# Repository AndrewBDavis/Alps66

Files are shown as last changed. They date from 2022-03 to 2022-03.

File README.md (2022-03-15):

ALPS 66% keyboard PCB
=====================
The primary goal of this project was to design a PCB and plate which fits in KBD66 and FC660m cases and supports FC660m, FC660c and 66% AEK style layouts.
The pcb schematic is modified from Hasu's Alps64.

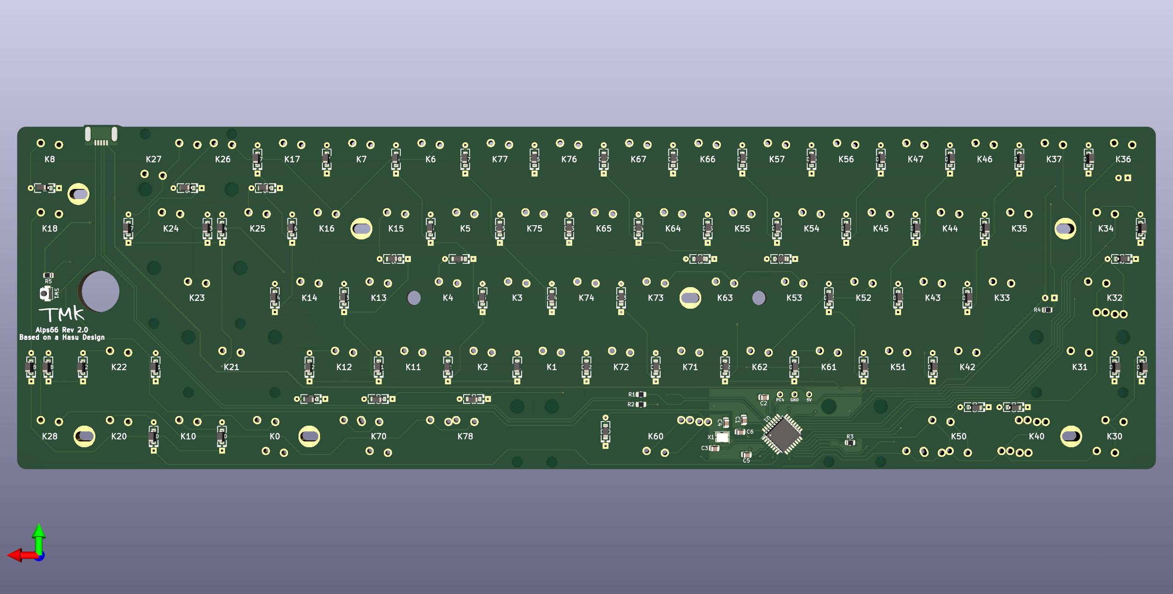
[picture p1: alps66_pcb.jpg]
alps66_pcb


original_b78a812e-5f5d-4627-9017-195e72d05074_PXL_20211022_134126410
Shown in FC660M case with prototype 1.2mm FR4 Plate in FC660C Layout

Supported Layouts
---------------
No ISO Enter (Especially ISO AEK)

Rev1 boards only:
	To utilize split backspace or 3rd key to the right of spacebar, you will need to solder bridge SJ1.
	To utilize the LED indicator, you will need to solder bridge SJ2 and modify files. 

Bottom row:
	1.5__1.0___1.5___6.5___1.5___1.5___1__1__1		(AEK with and 1u option key)

	1.5__1.25__1.5___6.25__1.5___1.5___1__1__1		(AEK Standard with 6.25 spacebar)

	1.5__1.25__1.5___5__1.5___1.25___1.5___1__1__1		(AEK Standard with 5 spacebar)
	
	1.25__1.25__1.25__6__1.25__1.25__1.25__1__1__1		(FC660c bottom row)
	
	1.25__1.0___1.25__6.25__1.25__1.25__1.25__1__1__1	(FC660m bottom row)

Caps lock:  
	0.75u  (Non Stepped)  
	0.25u  (Alps Dell/SGI Stepped)  
	0.125u (Cherry Stepped)  

Where key unit for rows: Esc[0u], 1[1u]...

Supported Cases
-------------
KBDFans KBD66 (confirmed)  
Leopold FC660m (confirmed)  
KBDFans KBD661 (unconfirmed)  

BOM for Alps66 keyboard                                                  
------------------
| REF:  | VALUE: | FOOTPRINT: | COMPONENT |
|--- | --- | --- | --- |
| C1 | 4.7u | C_0805 | |
| C2 | 1u | C_0805 | | 
| C3 | 22p | C_0805 | |
| C4 | 22p | C_0805 | |
| C5 | 0.1u | C_0805 | |
| C6 | 0.1u | C_0805 | |
| J1 | USB_mini_B | USB_miniB_hirose_5S8 | UX60SC-MB-5S8 Hirose |
| R1 | 22 | R_0805 | |
| R2 | 22 | R_0805 | |
| R3 | 10K | R_0805 | |
| R4 | 1K | R_0805 | |
| R5 | 10K | R_0805 | |
| SW100 | SW_PUSH | SW_SPST_B3U-1000P-B  | B3U-1000P-B |
| U1 | ATMEGA32U2 | QFP32 | ATMega32u2-AU | 
| X1 | CRYSTAL | FA-238 | 16MHz, 12PF |
| D(67) | DIODE | SOD-123 or Axial | 1N4148 |
| LED1  | LED | LED_D3.0mm | 3mm Round Top LED |

Revisions
-------------
V1.0: 	Initial Release  
V2.0: 	The switch holes are reduced from 2.05mm, no longer supporting 8134-HC-12P2 / 8134-HC-12P3 holtite sockets.  
&emsp;&emsp;&nbsp;&nbsp;Crystal Load Capacitance changed from 10pF to 12pF  
&emsp;&emsp;&nbsp;&nbsp;Changed C1 package size from 1206 to 0805  
&emsp;&emsp;&nbsp;&nbsp;Changed footprint library from Hasu's keyboard_parts to personal "Keyboard_Footprints" library  
&emsp;&emsp;&nbsp;&nbsp;Change ground plane configuration  
&emsp;&emsp;&nbsp;&nbsp;Moved diode D15 to allow added mounting location between K15 and K16  
&emsp;&emsp;&nbsp;&nbsp;Removed wider 6u stabilizer footprint spacing, narrower footprint is supported by SP and GMK  
&emsp;&emsp;&nbsp;&nbsp;Changed SMD led to standard through hole, adding provistions for SKCL in-switch LED on Esc key  
&emsp;&emsp;&nbsp;&nbsp;Changed matrix and removed solder jumpers  
&emsp;&emsp;&nbsp;&nbsp;Added Support for 1.5,1.25,1.5,5,1.5,1.25,1.5,1,1,1 bottom row

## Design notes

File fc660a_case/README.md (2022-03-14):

In progress  

Required hardware:  
6x M3x8mm Hex Standoff Spacers a corners  
2x M2x8mm Round Standoff Spacers at usb  
6x M2x8mm Rourd Standoff Spacers at plate mount  

6x M3x8 Countersunk Hex Socket Screws at corners top  
6x M3x8 Countersunk Hex Socket Screws at corners bottom  1
2x M2x4 Button Head Hex Socket Screws at usb, top  
2x M2X3 Countersunk Hex Socket Screws at usb, bottom  
6x M2x4 Button Head Hex Socket Screws at plate mount, top  
6x M2x3 Countersunk Hex Socket Screws at plate mount, bottom

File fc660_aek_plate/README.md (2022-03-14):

FR4 1.2mm plate files for use with Alps switches, AEK Keycaps, Alps plate-mount stabilizers and Alps66 pcb in KBD66 or Leopold FC660M plastic case

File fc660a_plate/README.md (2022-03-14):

FR4 1.2mm plate files for use with Alps switches, Cherry PCB-mount stabilizers and Alps66 pcb in KBD66 or Leopold FC660M plastic case

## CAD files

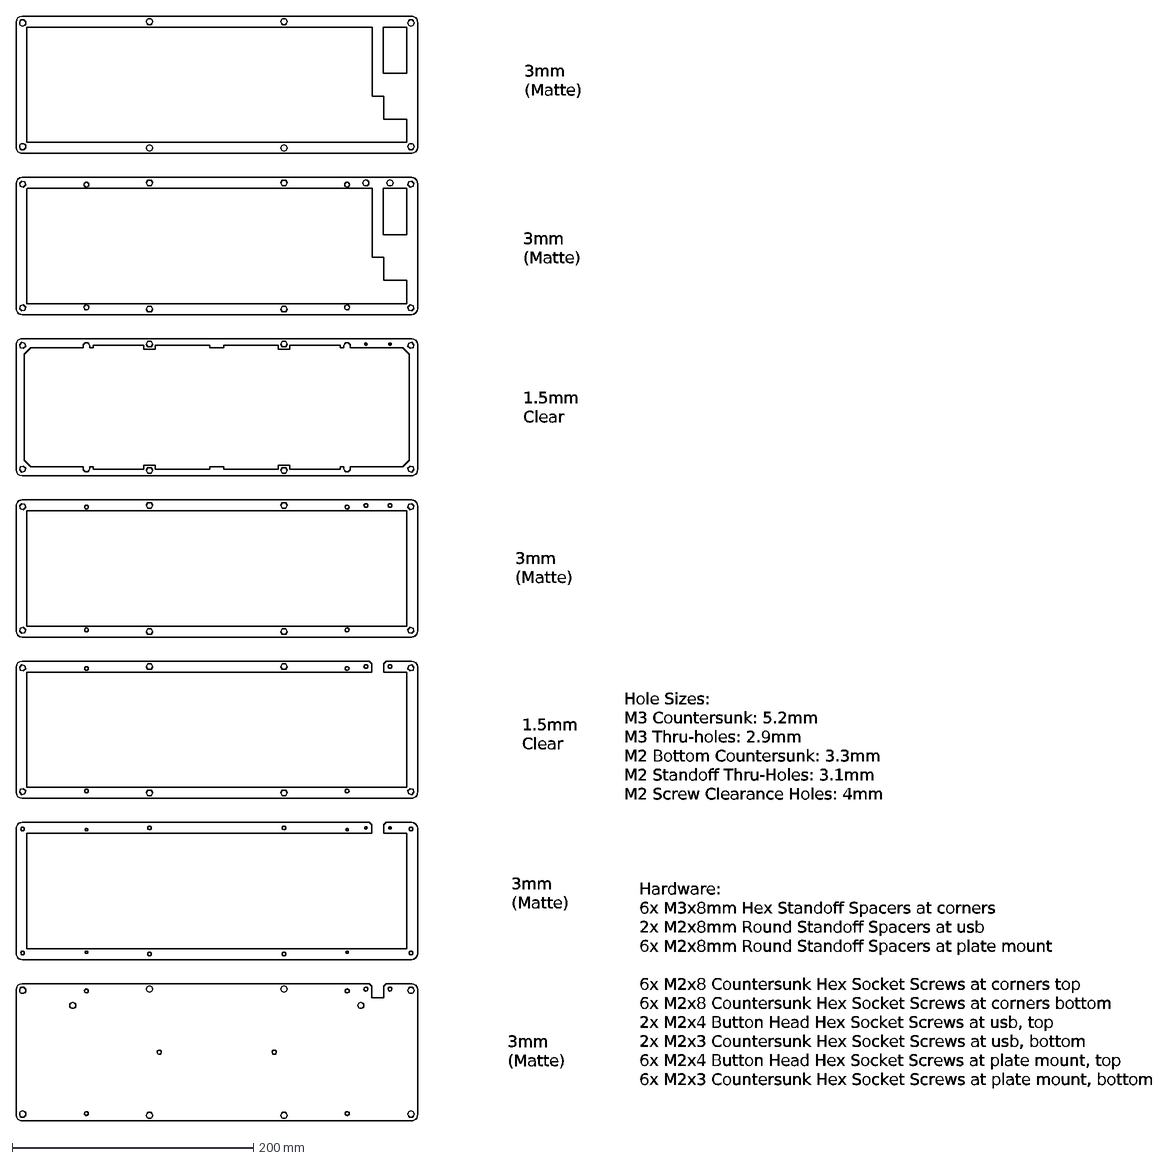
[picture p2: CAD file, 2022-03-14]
fc660a_case/fc660a_case.dxf
3mm (Matte)
1.5mm Clear
Hardware: 6x M3x8mm Hex Standoff Spacers at corners 2x M2x8mm Round Standoff Spacers at usb 6x M2x8mm Round Standoff Spacers at plate mount 6x M2x8 Countersunk 
Hole Sizes: M3 Countersunk: 5.2mm M3 Thru-holes: 2.9mm M2 Bottom Countersunk: 3.3mm M2 Standoff Thru-Holes: 3.1mm M2 Screw Clearance Holes: 4mm

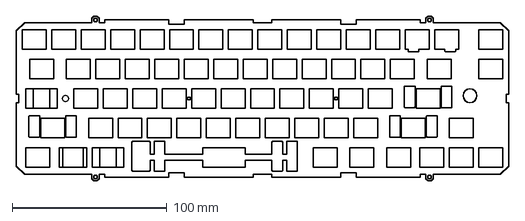
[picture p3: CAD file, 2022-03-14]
fc660a_plate/fc660a_plate.dxf
318.5 x 106.6 mm

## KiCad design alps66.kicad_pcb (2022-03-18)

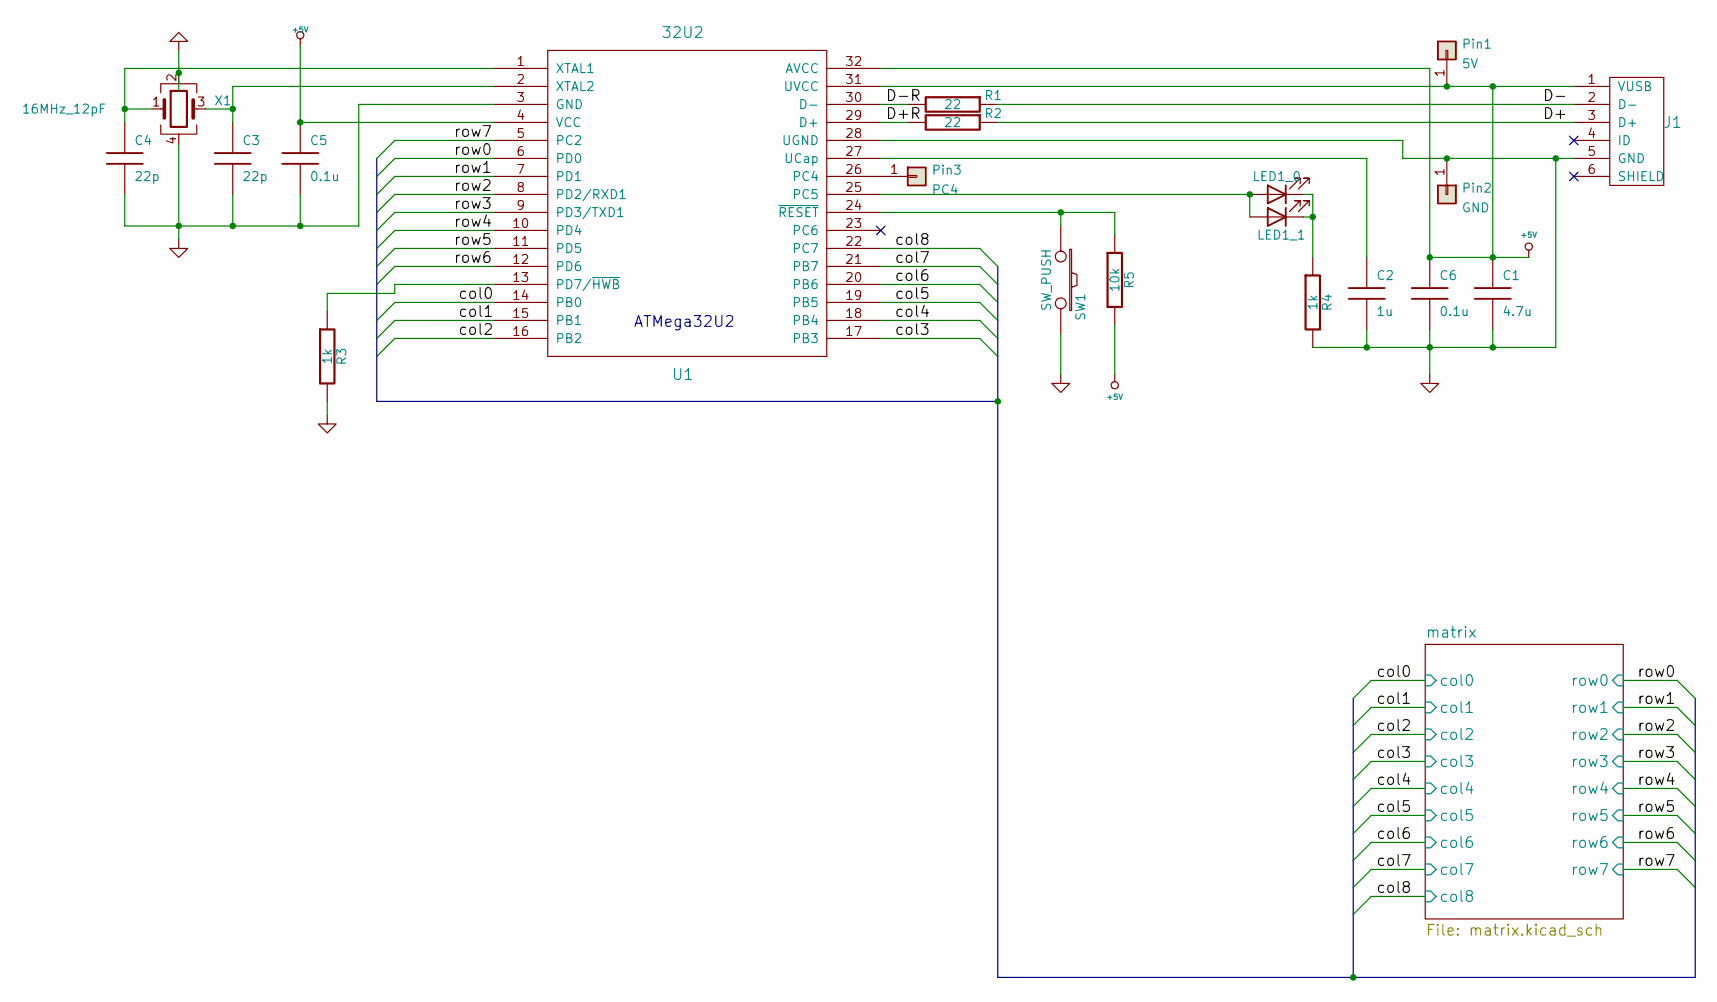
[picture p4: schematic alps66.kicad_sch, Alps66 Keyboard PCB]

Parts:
C1: 4.7u; C_0805_2012Metric
C2: 1u; C_0805_2012Metric
C3, C4: 22p; C_0805_2012Metric
C5, C6: 0.1u; C_0805_2012Metric
J1: USB_mini_micro_B; USB_miniB_hirose_5S8
LED1_0: 3mm; LED_D3.0mm
LED1_1: 5mm_Rectangular; LED_Rectangular_W5.0mm_H2.0mm
Pin1: 5V; Pin
Pin2: GND; Pin
Pin3: PC4; Pin
R1, R2: 22; R_0805_2012Metric
R3, R4: 1k; R_0805_2012Metric
R5: 10k; R_0805_2012Metric
SW1: SW_PUSH; SW_SPST_B3U-1000P-B
U1: 32U2; LQFP-32_7x7mm_P0.8mm
X1: 16MHz_12pF; Crystal_SMD_SeikoEpson_FA238-4Pin_3.2x2.5mm

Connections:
+5V: C1.1, C5.1, C6.1, J1.1 (VUSB), Pin1.1, R5.2, U1.4 (VCC), U1.31 (UVCC), U1.32 (AVCC)
/D+: J1.3 (D+), R2.1
/D+R: R2.2, U1.29 (D+)
/D-: J1.2 (D-), R1.1
/D-R: R1.2, U1.30 (D-)
/col0: U1.14 (PB0); also elsewhere on the board
/col1: U1.15 (PB1); also elsewhere on the board
/col2: U1.16 (PB2); also elsewhere on the board
/col3: U1.17 (PB3); also elsewhere on the board
/col4: U1.18 (PB4); also elsewhere on the board
/col5: U1.19 (PB5); also elsewhere on the board
/col6: U1.20 (PB6); also elsewhere on the board
/col7: U1.21 (PB7); also elsewhere on the board
/col8: U1.22 (PC7); also elsewhere on the board
/row0: U1.6 (PD0); also elsewhere on the board
/row1: U1.7 (PD1); also elsewhere on the board
/row2: U1.8 (PD2/RXD1); also elsewhere on the board
/row3: U1.9 (PD3/TXD1); also elsewhere on the board
/row4: U1.10 (PD4); also elsewhere on the board
/row5: U1.11 (PD5); also elsewhere on the board
/row6: U1.12 (PD6); also elsewhere on the board
/row7: U1.5 (PC2); also elsewhere on the board
GND: C1.2, C2.2, C3.2, C4.2, C5.2, C6.2, J1.5 (GND), Pin2.1, R3.2, R4.2, SW1.2, U1.3 (GND), U1.28 (UGND), X1.2, X1.4
unnamed: C2.1, U1.27 (UCap)
unnamed: C3.1, U1.2 (XTAL2), X1.3
unnamed: C4.1, U1.1 (XTAL1), X1.1
unnamed: LED1_0.1 (K), LED1_1.1 (K), R4.1
unnamed: LED1_0.2 (A), LED1_1.2 (A), U1.25 (PC5)
unnamed: Pin3.1, U1.26 (PC4)
unnamed: R3.1, U1.13 (PD7/~HWB)
unnamed: R5.1, SW1.1, U1.24 (~RESET)

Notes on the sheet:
ATMega32U2

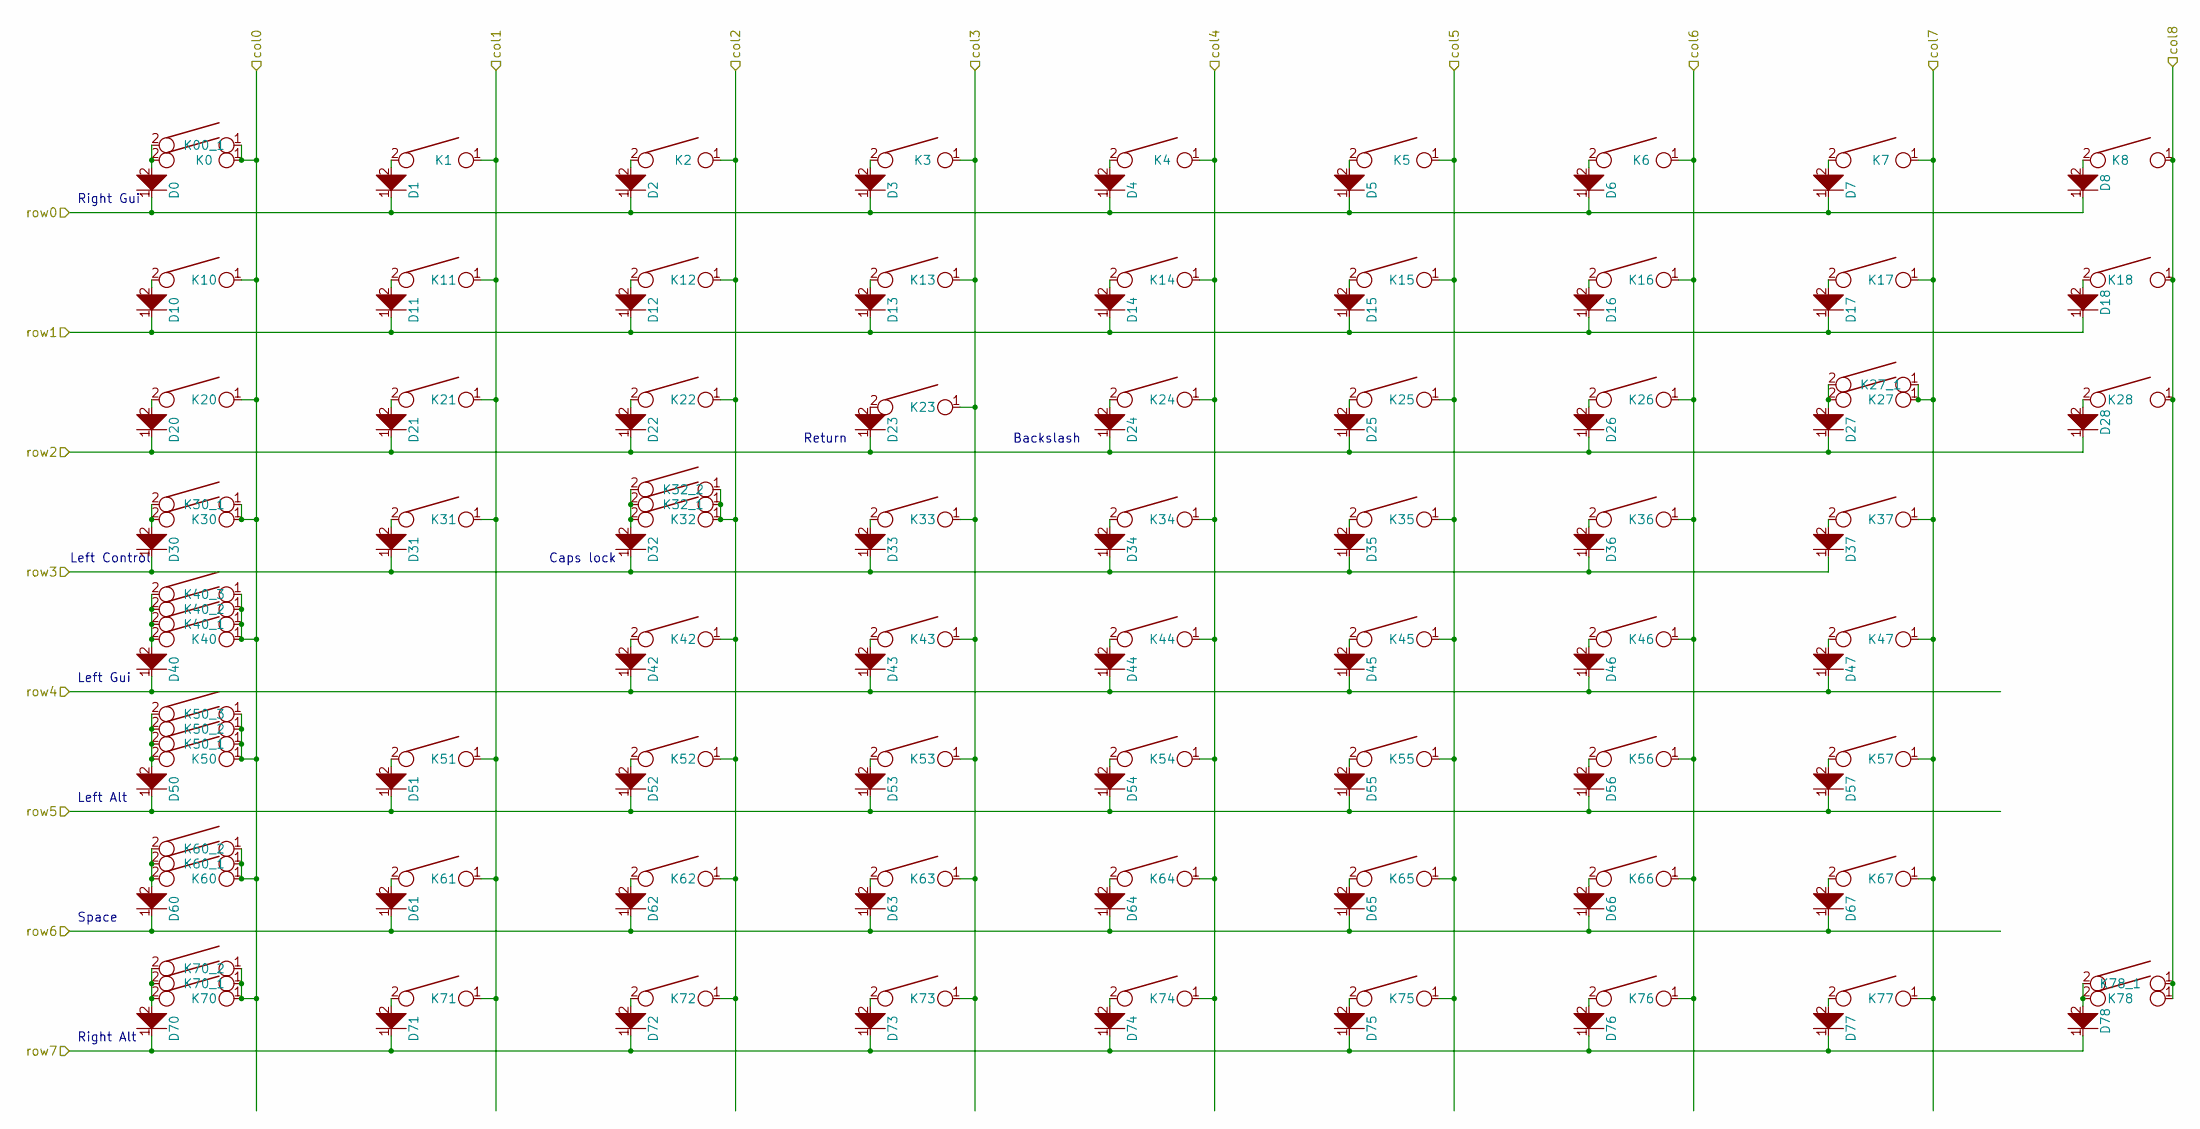
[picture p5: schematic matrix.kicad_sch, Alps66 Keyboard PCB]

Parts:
D0, D1, D2, D3, D4, D5, D6, D7, D8, D10, D11, D12, D13, D14, D15, D16, D17, D18, D20, D21, D22, D23, D24, D25, D26, D27, D28, D30, D31, D32, D33, D34, D35, D36, D37, D40, D42, D43, D44, D45, D46, D47, D50, D51, D52, D53, D54, D55, D56, D57, D60, D61, D62, D63, D64, D65, D66, D67, D70, D71, D72, D73, D74, D75, D76, D77, D78: D; Diode_123_Axial
K0, K1, K2, K3, K4, K5, K6, K7, K8, K10, K11, K12, K13, K14, K15, K16, K17, K18, K20, K21, K22, K23, K24, K25, K26, K27, K28, K30, K31, K32, K33, K34, K35, K36, K37, K40, K42, K43, K44, K45, K46, K47, K50, K51, K52, K53, K54, K55, K56, K57, K60, K61, K62, K63, K64, K65, K66, K67, K70, K71, K72, K73, K74, K75, K76, K77, K78: KEYSW; Alps
K00_1, K27_1, K30_1, K32_1, K32_2, K40_1, K40_2, K40_3, K50_3, K70_1: KEYSW; Alps_Secondary
K50_1, K50_2, K60_1, K60_2, K70_2, K78_1: KEYSW; Alps_Secondary_Reversed

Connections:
/col0: K0.1, K00_1.1, K10.1, K20.1, K30.1, K30_1.1, K40.1, K40_1.1, K40_2.1, K40_3.1, K50.1, K50_1.1, K50_2.1, K50_3.1, K60.1, K60_1.1, K60_2.1, K70.1, K70_1.1, K70_2.1; also elsewhere on the board
/col1: K1.1, K11.1, K21.1, K31.1, K51.1, K61.1, K71.1; also elsewhere on the board
/col2: K2.1, K12.1, K22.1, K32.1, K32_1.1, K32_2.1, K42.1, K52.1, K62.1, K72.1; also elsewhere on the board
/col3: K3.1, K13.1, K23.1, K33.1, K43.1, K53.1, K63.1, K73.1; also elsewhere on the board
/col4: K4.1, K14.1, K24.1, K34.1, K44.1, K54.1, K64.1, K74.1; also elsewhere on the board
/col5: K5.1, K15.1, K25.1, K35.1, K45.1, K55.1, K65.1, K75.1; also elsewhere on the board
/col6: K6.1, K16.1, K26.1, K36.1, K46.1, K56.1, K66.1, K76.1; also elsewhere on the board
/col7: K7.1, K17.1, K27.1, K27_1.1, K37.1, K47.1, K57.1, K67.1, K77.1; also elsewhere on the board
/col8: K8.1, K18.1, K28.1, K78.1, K78_1.1; also elsewhere on the board
/row0: D0.1, D1.1, D2.1, D3.1, D4.1, D5.1, D6.1, D7.1, D8.1; also elsewhere on the board
/row1: D10.1, D11.1, D12.1, D13.1, D14.1, D15.1, D16.1, D17.1, D18.1; also elsewhere on the board
/row2: D20.1, D21.1, D22.1, D23.1, D24.1, D25.1, D26.1, D27.1, D28.1; also elsewhere on the board
/row3: D30.1, D31.1, D32.1, D33.1, D34.1, D35.1, D36.1, D37.1; also elsewhere on the board
/row4: D40.1, D42.1, D43.1, D44.1, D45.1, D46.1, D47.1; also elsewhere on the board
/row5: D50.1, D51.1, D52.1, D53.1, D54.1, D55.1, D56.1, D57.1; also elsewhere on the board
/row6: D60.1, D61.1, D62.1, D63.1, D64.1, D65.1, D66.1, D67.1; also elsewhere on the board
/row7: D70.1, D71.1, D72.1, D73.1, D74.1, D75.1, D76.1, D77.1, D78.1; also elsewhere on the board
unnamed: D0.2, K0.2, K00_1.2
unnamed: D1.2, K1.2
unnamed: D2.2, K2.2
unnamed: D3.2, K3.2
unnamed: D4.2, K4.2
unnamed: D5.2, K5.2
unnamed: D6.2, K6.2
unnamed: D7.2, K7.2
unnamed: D8.2, K8.2
unnamed: D10.2, K10.2
unnamed: D11.2, K11.2
unnamed: D12.2, K12.2
unnamed: D13.2, K13.2
unnamed: D14.2, K14.2
unnamed: D15.2, K15.2
unnamed: D16.2, K16.2
unnamed: D17.2, K17.2
unnamed: D18.2, K18.2
unnamed: D20.2, K20.2
unnamed: D21.2, K21.2
unnamed: D22.2, K22.2
unnamed: D23.2, K23.2
unnamed: D24.2, K24.2
unnamed: D25.2, K25.2
unnamed: D26.2, K26.2
unnamed: D27.2, K27.2, K27_1.2
unnamed: D28.2, K28.2
unnamed: D30.2, K30.2, K30_1.2
unnamed: D31.2, K31.2
unnamed: D32.2, K32.2, K32_1.2, K32_2.2
unnamed: D33.2, K33.2
unnamed: D34.2, K34.2
unnamed: D35.2, K35.2
unnamed: D36.2, K36.2
unnamed: D37.2, K37.2
unnamed: D40.2, K40.2, K40_1.2, K40_2.2, K40_3.2
unnamed: D42.2, K42.2
unnamed: D43.2, K43.2
unnamed: D44.2, K44.2
unnamed: D45.2, K45.2
unnamed: D46.2, K46.2
unnamed: D47.2, K47.2
unnamed: D50.2, K50.2, K50_1.2, K50_2.2, K50_3.2
unnamed: D51.2, K51.2
unnamed: D52.2, K52.2
unnamed: D53.2, K53.2
unnamed: D54.2, K54.2
unnamed: D55.2, K55.2
unnamed: D56.2, K56.2
unnamed: D57.2, K57.2
unnamed: D60.2, K60.2, K60_1.2, K60_2.2
unnamed: D61.2, K61.2
unnamed: D62.2, K62.2
unnamed: D63.2, K63.2
unnamed: D64.2, K64.2
unnamed: D65.2, K65.2
unnamed: D66.2, K66.2
unnamed: D67.2, K67.2
unnamed: D70.2, K70.2, K70_1.2, K70_2.2
unnamed: D71.2, K71.2
unnamed: D72.2, K72.2
unnamed: D73.2, K73.2
unnamed: D74.2, K74.2
unnamed: D75.2, K75.2
unnamed: D76.2, K76.2
unnamed: D77.2, K77.2
unnamed: D78.2, K78.2, K78_1.2

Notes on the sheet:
Backslash
Left Gui
Right Gui
Caps lock
Left Control
Space
Return
Left Alt
Right Alt

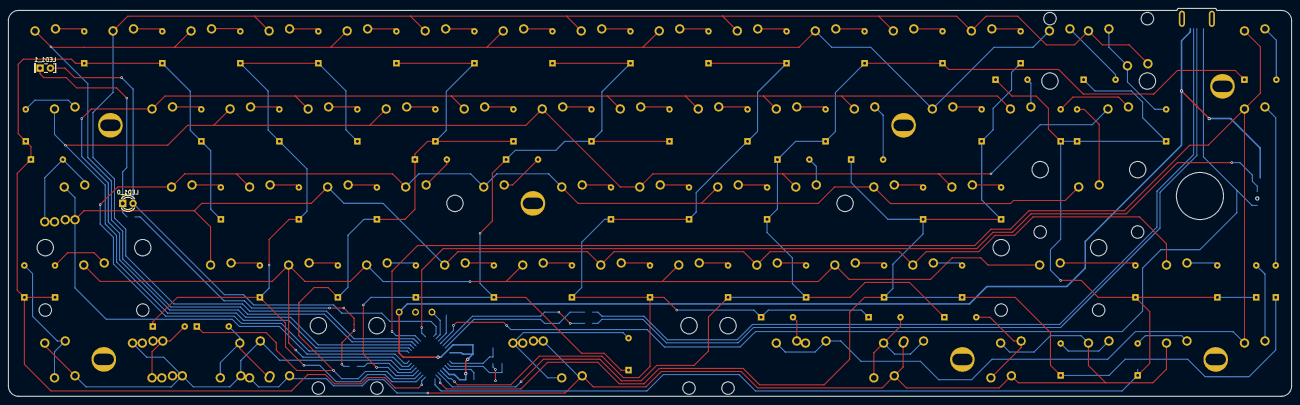
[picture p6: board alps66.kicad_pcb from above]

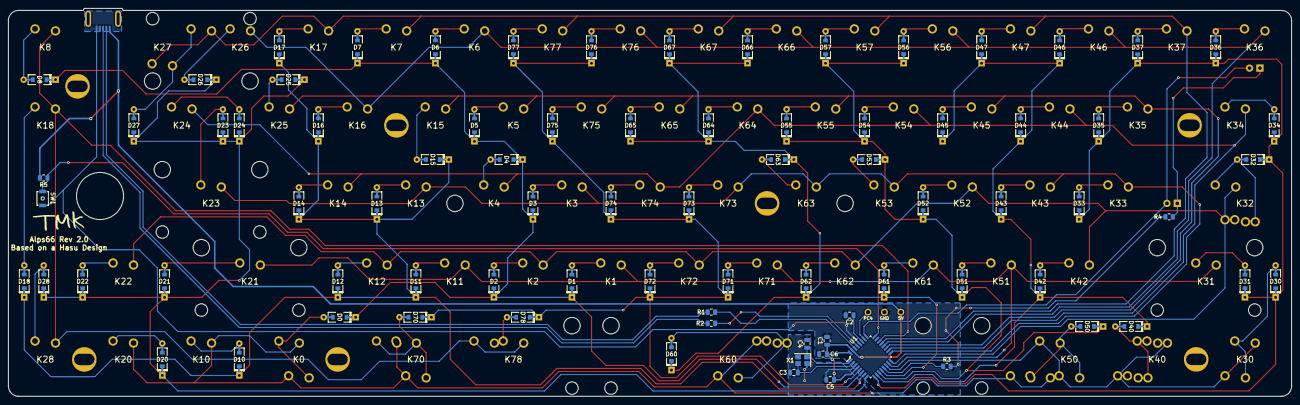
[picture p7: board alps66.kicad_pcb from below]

Board: 2 copper layers, 313.3 x 94.7 mm, 183 parts (82 on the bottom side), 98 nets.

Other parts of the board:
2u, 2u#2, 2u#3, 2u#4: 2u_stab
6.25u_stab: 6.25u_stab
6u_stab: 6u_stab_SP
Oval_Mounting_Hole: Oval_Mounting_Hole
Oval_Mounting_Hole#2, Oval_Mounting_Hole#3, Oval_Mounting_Hole#4, Oval_Mounting_Hole#5, Oval_Mounting_Hole#6, Oval_Mounting_Hole#7: Oval_Mounting_Hole

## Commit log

2022-03-14 Initial Release
    [clueboardPlateSplitRightShift.dxf, fc660a_acrylic_case.dxf]
2022-03-14 directory changes
    [clueboardPlateSplitRightShift.dxf, fc660a_case.dxf]
2022-03-18 Update Axial_Diode Footprint
    [alps66.kicad_pcb]
